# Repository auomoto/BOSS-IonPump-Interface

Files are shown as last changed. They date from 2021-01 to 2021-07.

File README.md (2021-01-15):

# BOSS-IonPump-Interface
The BOSS CCD dewars use a Modion C-1765V 2l/s ion pump with a custom vacuum fitting. This model number is not on the current modionvacuum.com website but the C-1765M looks similar.
The power supply is a Modion C-1766Q, which supplies the high voltage and also presents an analog signal indicating internal current that can be used as a vacuum pressure measurement. This power supply has an unusual 5-pin connector with a wall plug-in supply to supply power and also break out the signals.
To distribute the signals to the BOSS motion controller system (specMech) we use an interface box that supplies isolated 15 V to the two ion pumps (one on each of the two dewars) and conditions the analog signal for transmission to the control system.
[Link to the interface board description](https://docs.google.com/document/d/1ESppHA3kPF6aFfvCehlsRecCQ0mpgMWIIbT9OZ6ddFA/edit#)

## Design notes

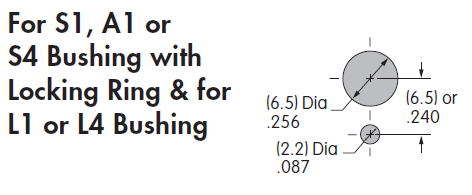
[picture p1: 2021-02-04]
Hardware/Enclosure/NKK Switch Panel Opening.png

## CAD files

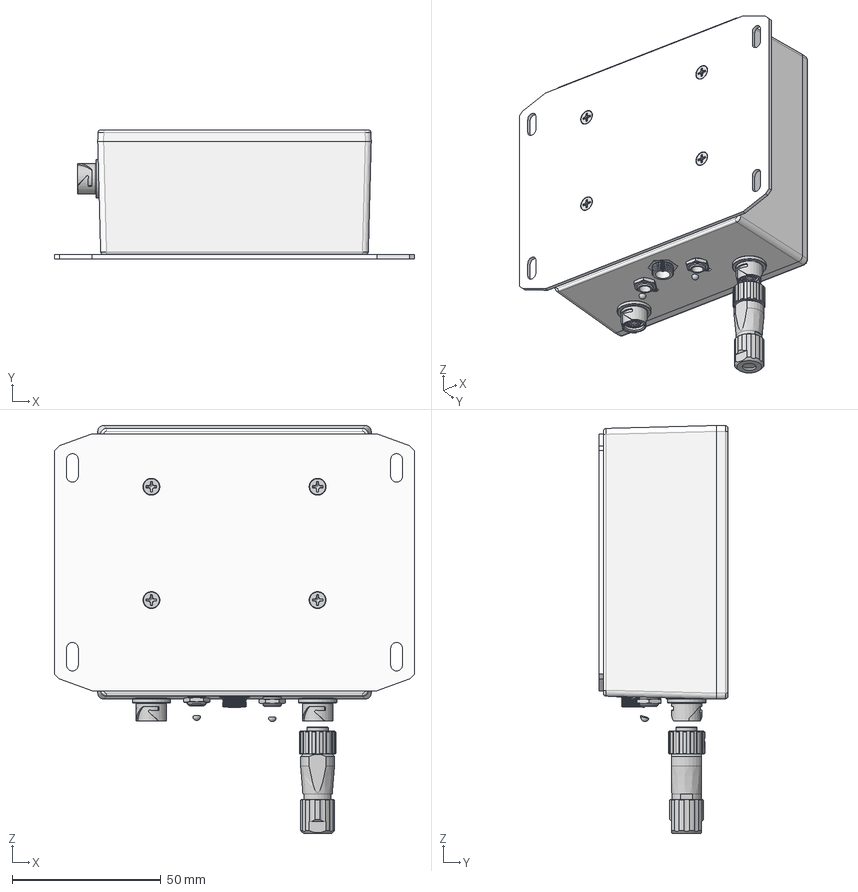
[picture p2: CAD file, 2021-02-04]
Hardware/Enclosure/BOSS Ion Pump Interface Assembly v27.step
121.2 x 43.5 x 137.2 mm
1/4 inch 91771A106_18-8 SS FLAT HEAD PHILLIPS MACHINE SCREW x 4
3/8 inch 91115A509_18-8 SS FEM THRDED HEX STANDOFF x 4
LF07WBR-6S x 2
Hirose LF07WBR-6P
CUI_DEVICES_PJ-005A
1590Y Box
1590Y Lid
1590Y Flange
LF07WBP-6P

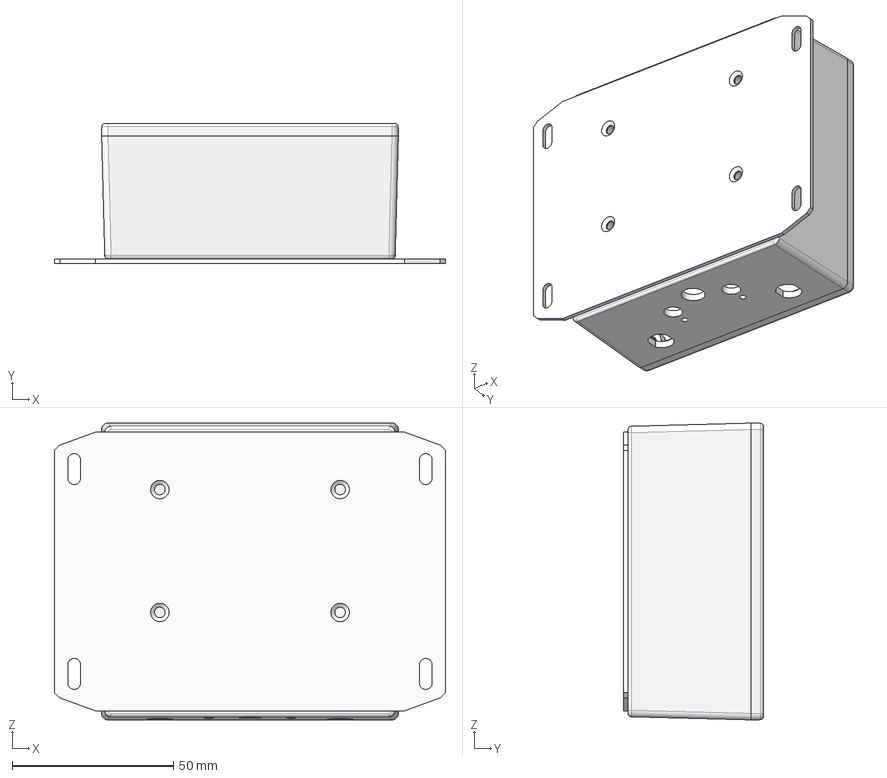
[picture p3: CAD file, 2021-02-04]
Hardware/Enclosure/1590YF Modified v1.step
121.2 x 43.5 x 92.0 mm
1590Y Box
1590Y Lid
1590Y Flange

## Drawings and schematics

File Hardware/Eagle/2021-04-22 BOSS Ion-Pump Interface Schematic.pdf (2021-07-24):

J2

# 2021-04-22 BOSS-Ion-Pump-Interface

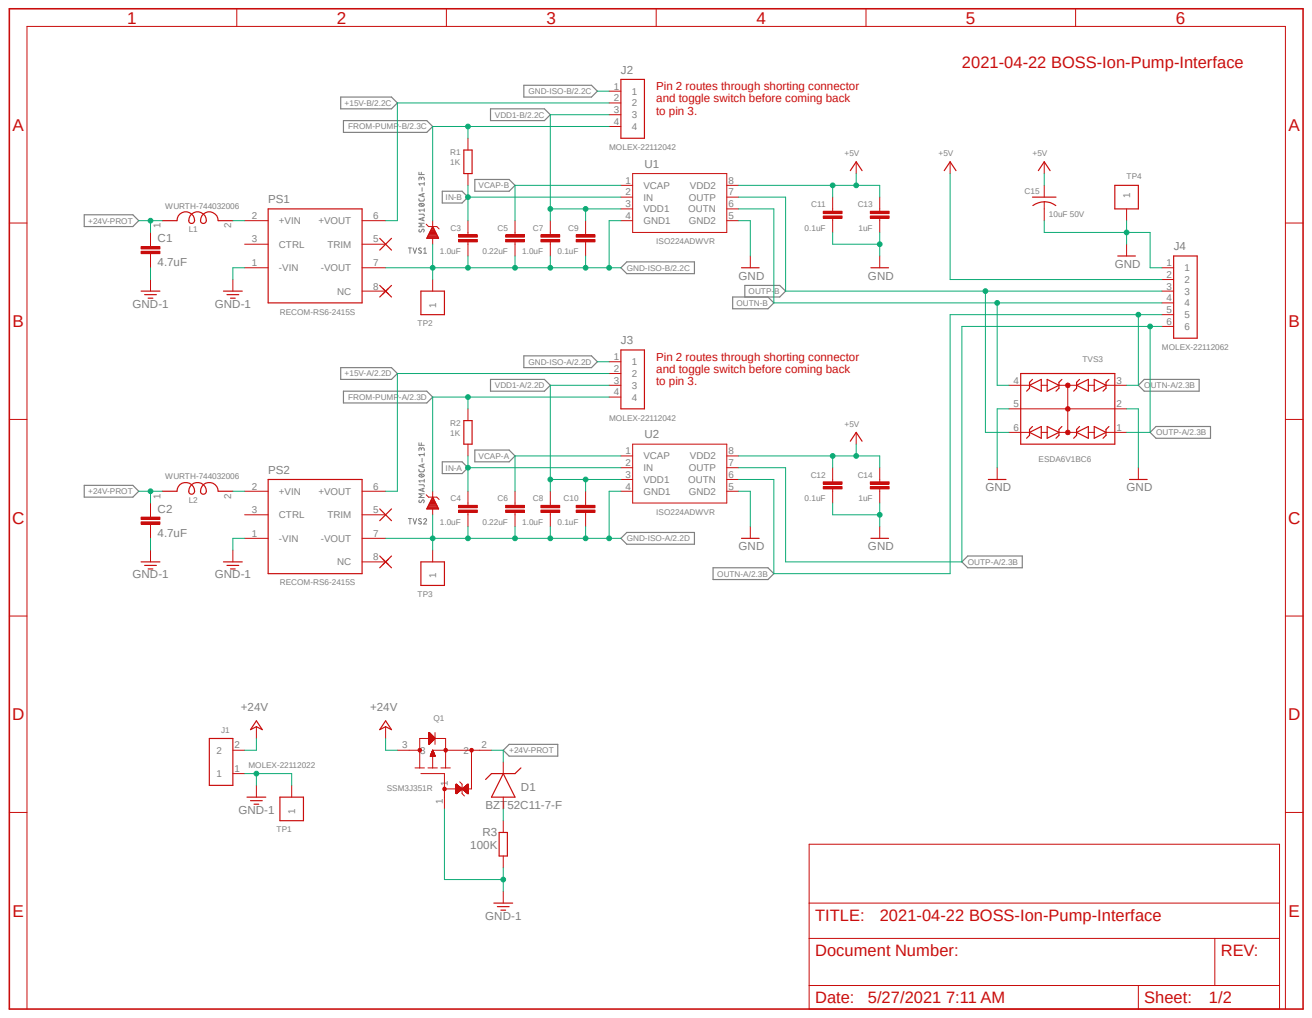
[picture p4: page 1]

2021-04-22 BOSS-Ion-Pump-Interface

Document Number: | REV:

Date: 5/27/2021 7:11 AM | Sheet: 1/2

A

A

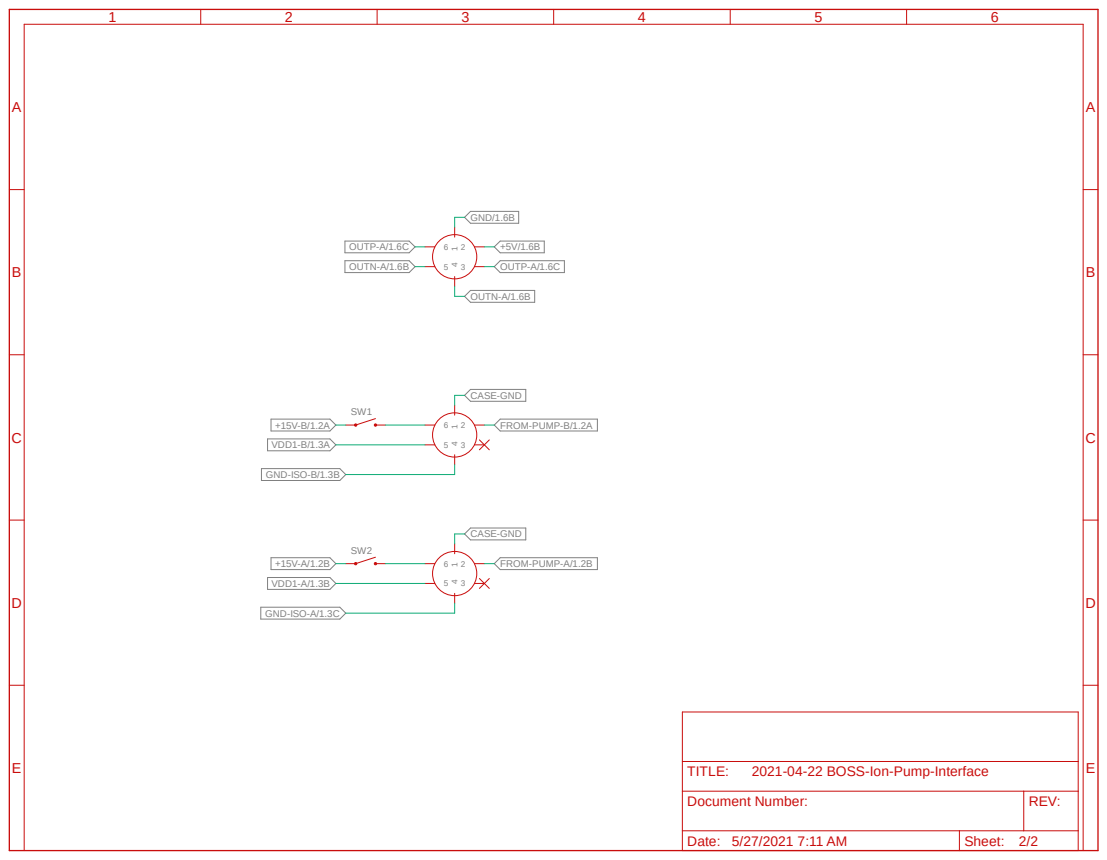
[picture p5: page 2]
VDD1-B/1.3A; GND-ISO-B/1.3B; FROM-PUMP-B/1.2A; CASE-GND; VDD1-A/1.3B; GND-ISO-A/1.3C; FROM-PUMP-A/1.2B; GND/1.6B; OUTP-A/1.6C; OUTN-A/1.6B; TITLE:

2021-04-22 BOSS-Ion-Pump-Interface

Document Number: | REV:

Date: 5/27/2021 7:11 AM | Sheet: 2/2

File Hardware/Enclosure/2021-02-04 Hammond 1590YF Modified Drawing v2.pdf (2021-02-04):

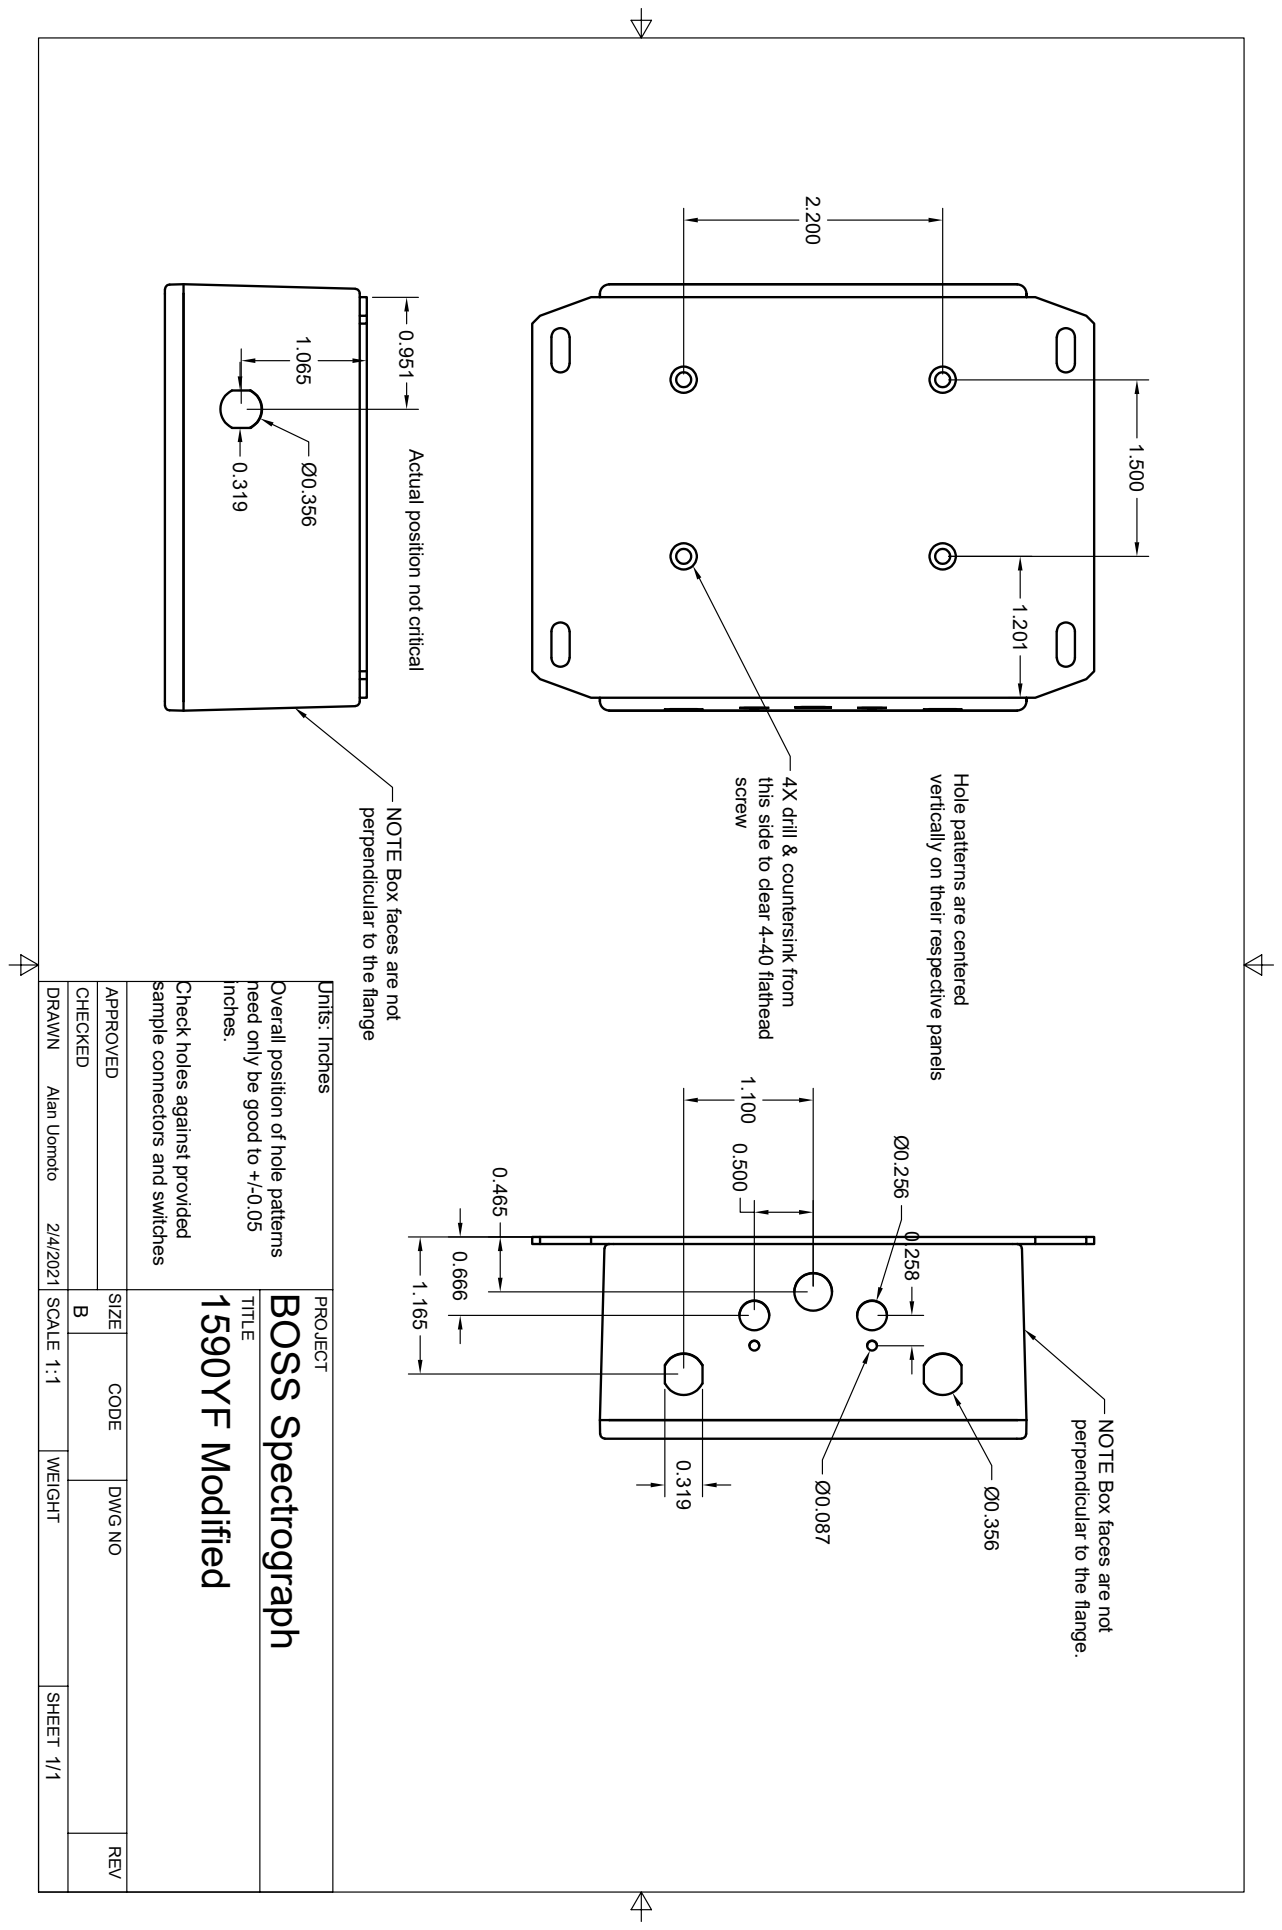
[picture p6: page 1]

TITLE PROJECT DRAWN CHECKED APPROVED SCALE WEIGHT SHEET DWG NO REV CODE SIZE 1/1 1:1 2/4/2021 Alan Uomoto B1590YF Modified BOSS Spectrograph 1.500 2.200 1.201 0.319 Ø0.356 1.065 0.465 0.6661.165 0.500 1.100 Ø0.356 Ø0.256 Ø0.087 0.258 0.319 0.951 vertically on their respective panels Hole patterns are centered Actual position not critical screw this side to clear 4-40 flathead 4X drill & countersink fromsample connectors and switches Check holes against provided inches. need only be good to +/-0.05 Overall position of hole patterns Units: Inches perpendicular to the flange. NOTE Box faces are not perpendicular to the flange NOTE Box faces are not

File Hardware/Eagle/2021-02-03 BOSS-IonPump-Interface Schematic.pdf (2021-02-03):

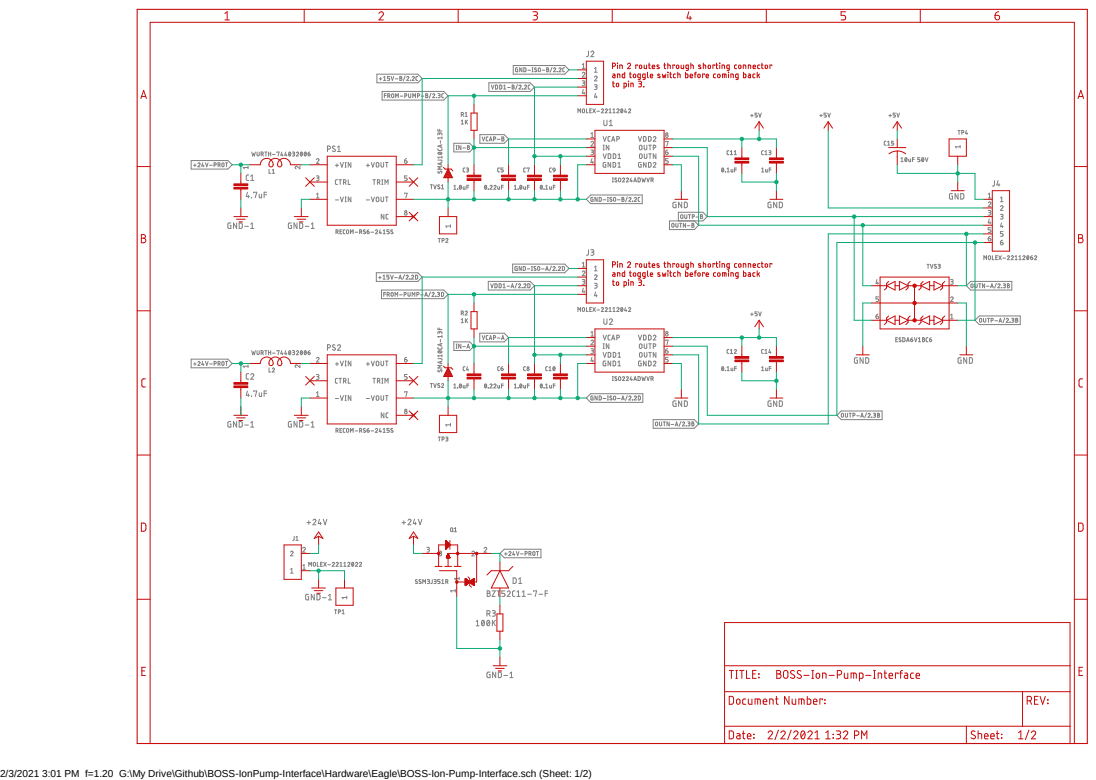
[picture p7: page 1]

2/3/2021 3:01 PM f=1.20 G:\My Drive\Github\BOSS-IonPump-Interface\Hardware\Eagle\BOSS-Ion-Pump-Interface.sch (Sheet: 1/2)

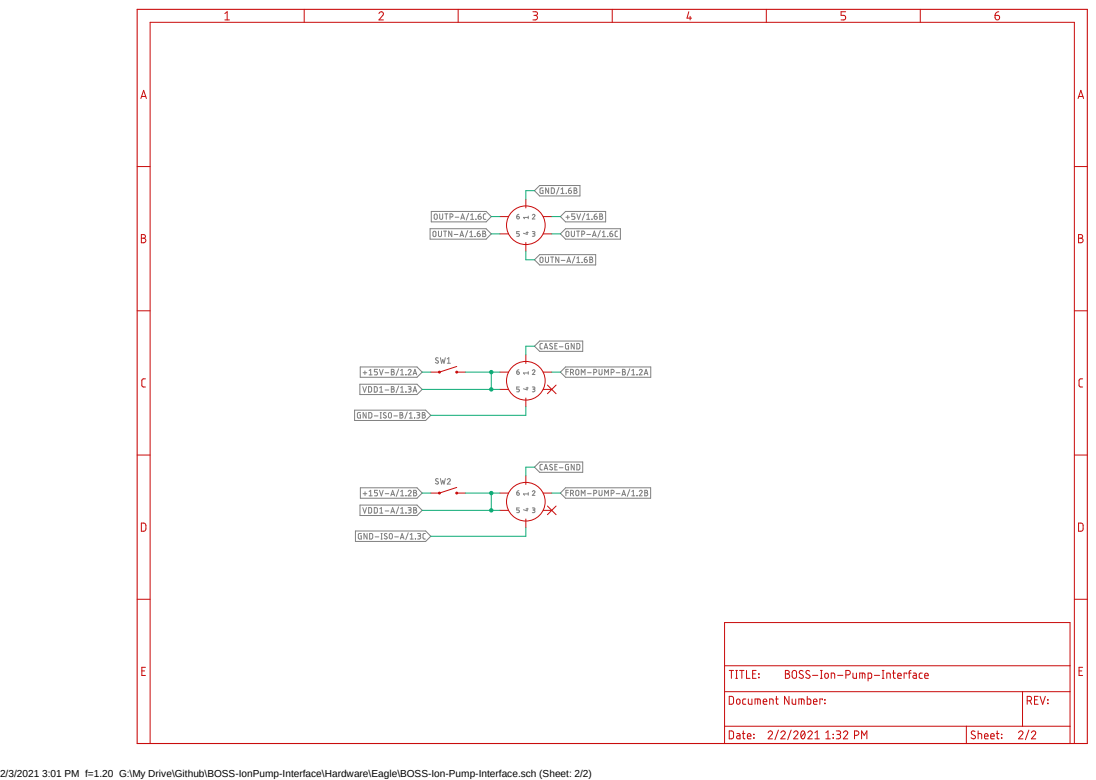
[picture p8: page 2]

2/3/2021 3:01 PM f=1.20 G:\My Drive\Github\BOSS-IonPump-Interface\Hardware\Eagle\BOSS-Ion-Pump-Interface.sch (Sheet: 2/2)

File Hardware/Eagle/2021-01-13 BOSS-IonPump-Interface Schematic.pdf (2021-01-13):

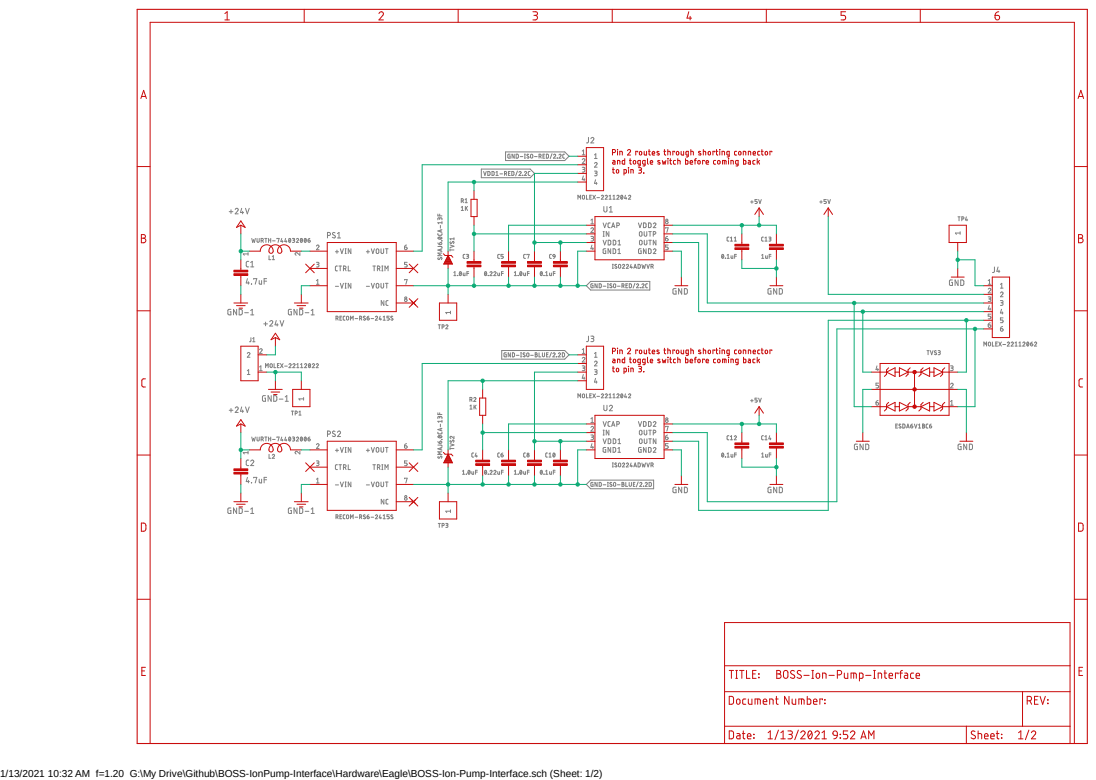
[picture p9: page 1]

1/13/2021 10:32 AM f=1.20 G:\My Drive\Github\BOSS-IonPump-Interface\Hardware\Eagle\BOSS-Ion-Pump-Interface.sch (Sheet: 1/2)

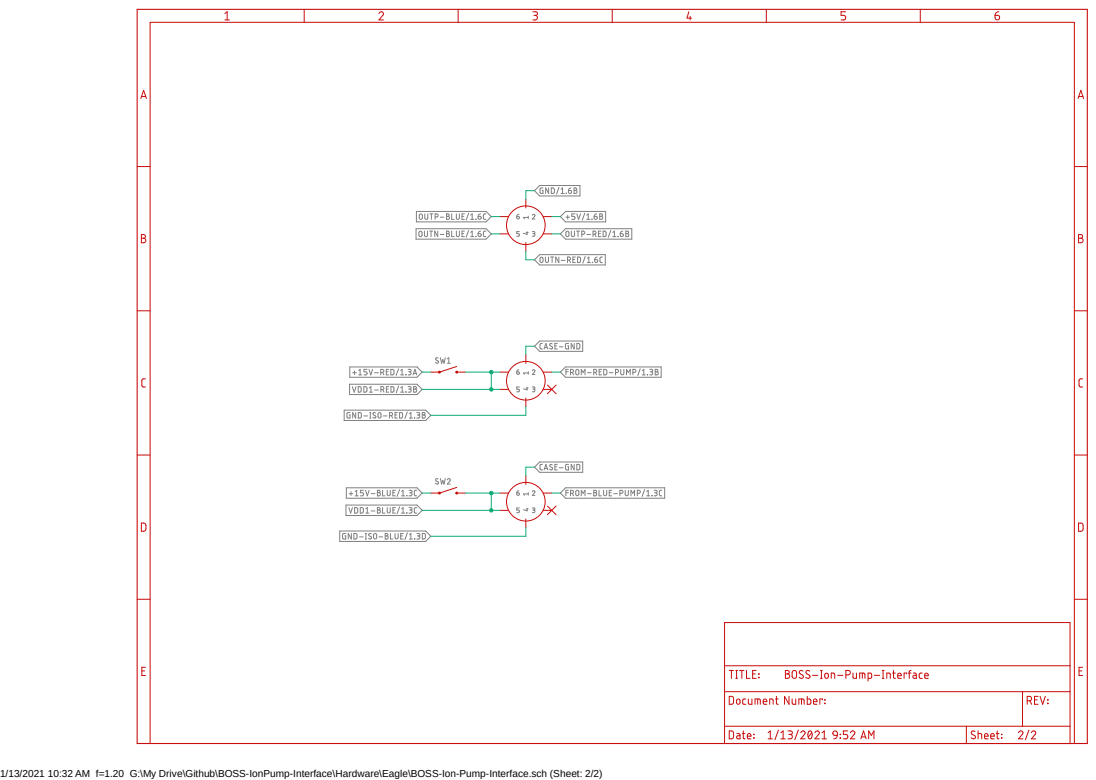
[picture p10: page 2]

1/13/2021 10:32 AM f=1.20 G:\My Drive\Github\BOSS-IonPump-Interface\Hardware\Eagle\BOSS-Ion-Pump-Interface.sch (Sheet: 2/2)

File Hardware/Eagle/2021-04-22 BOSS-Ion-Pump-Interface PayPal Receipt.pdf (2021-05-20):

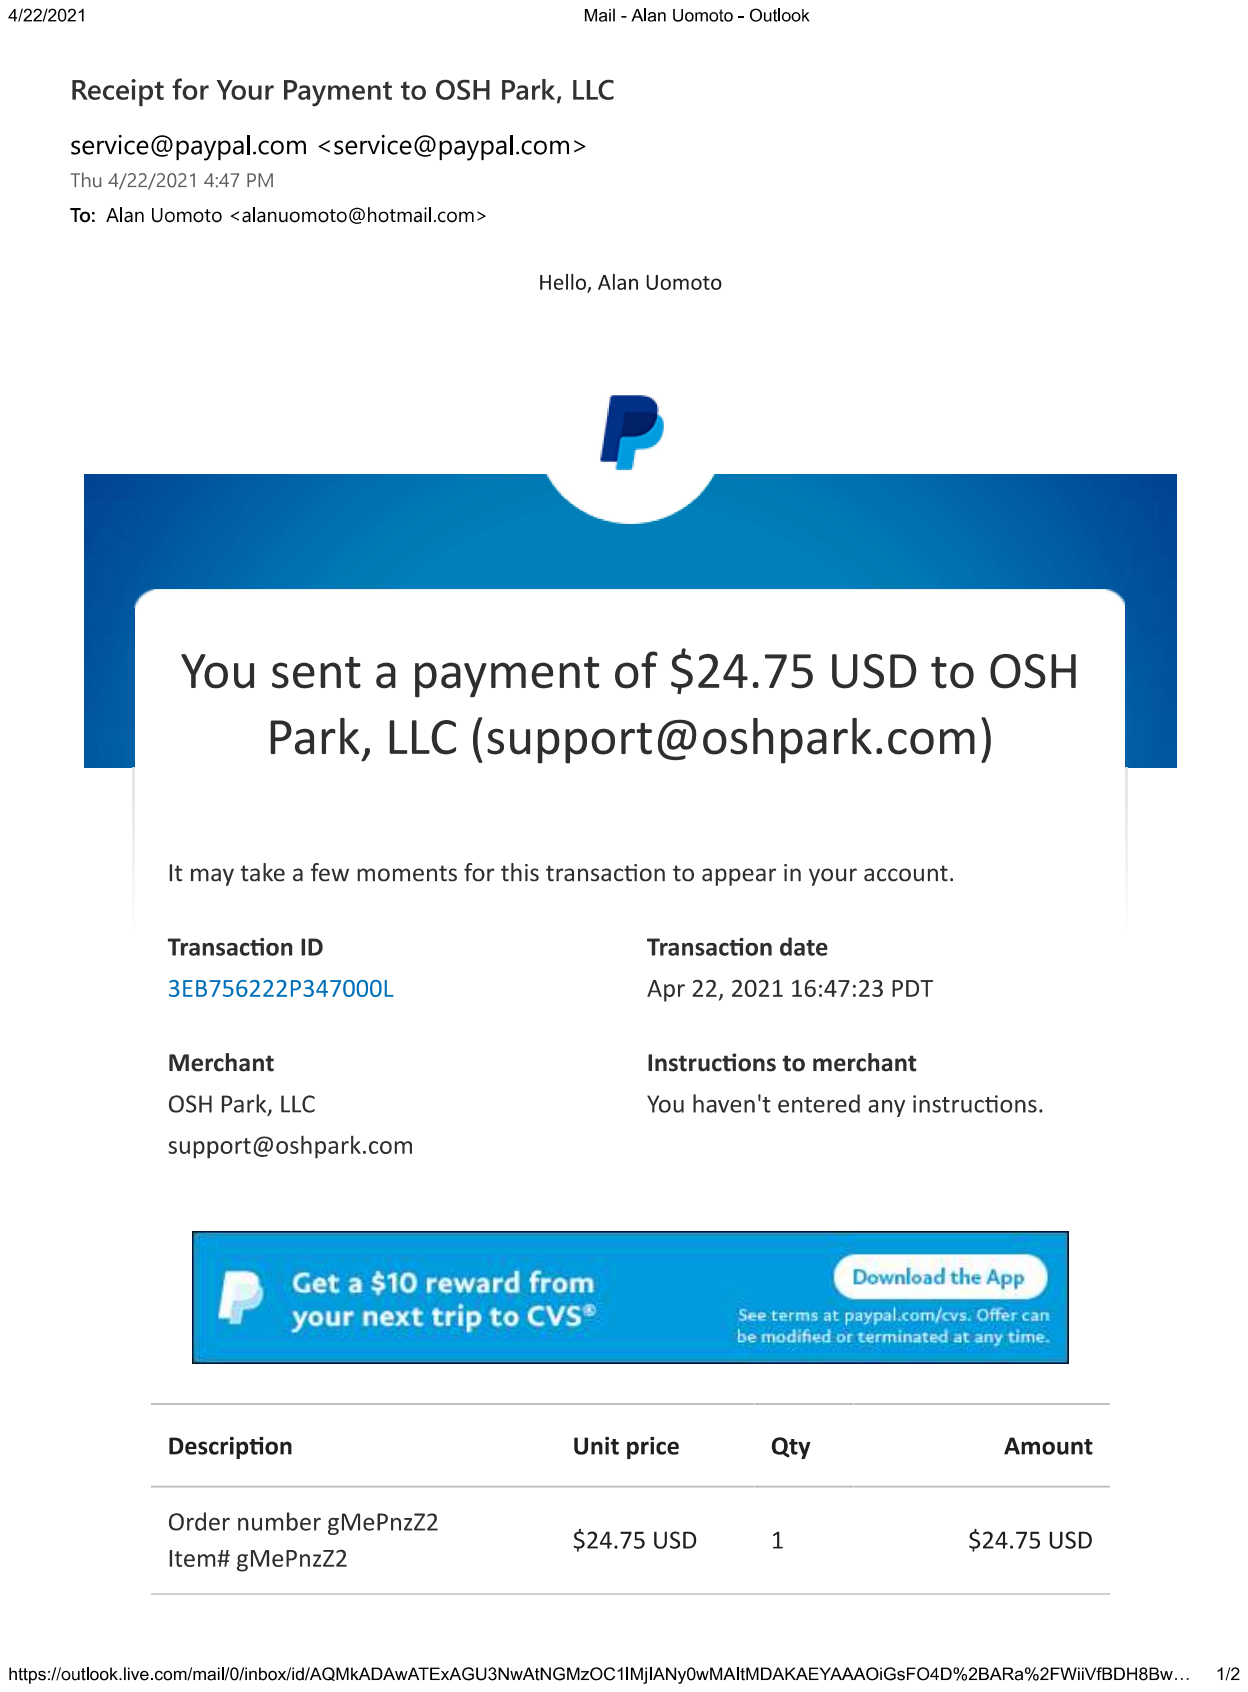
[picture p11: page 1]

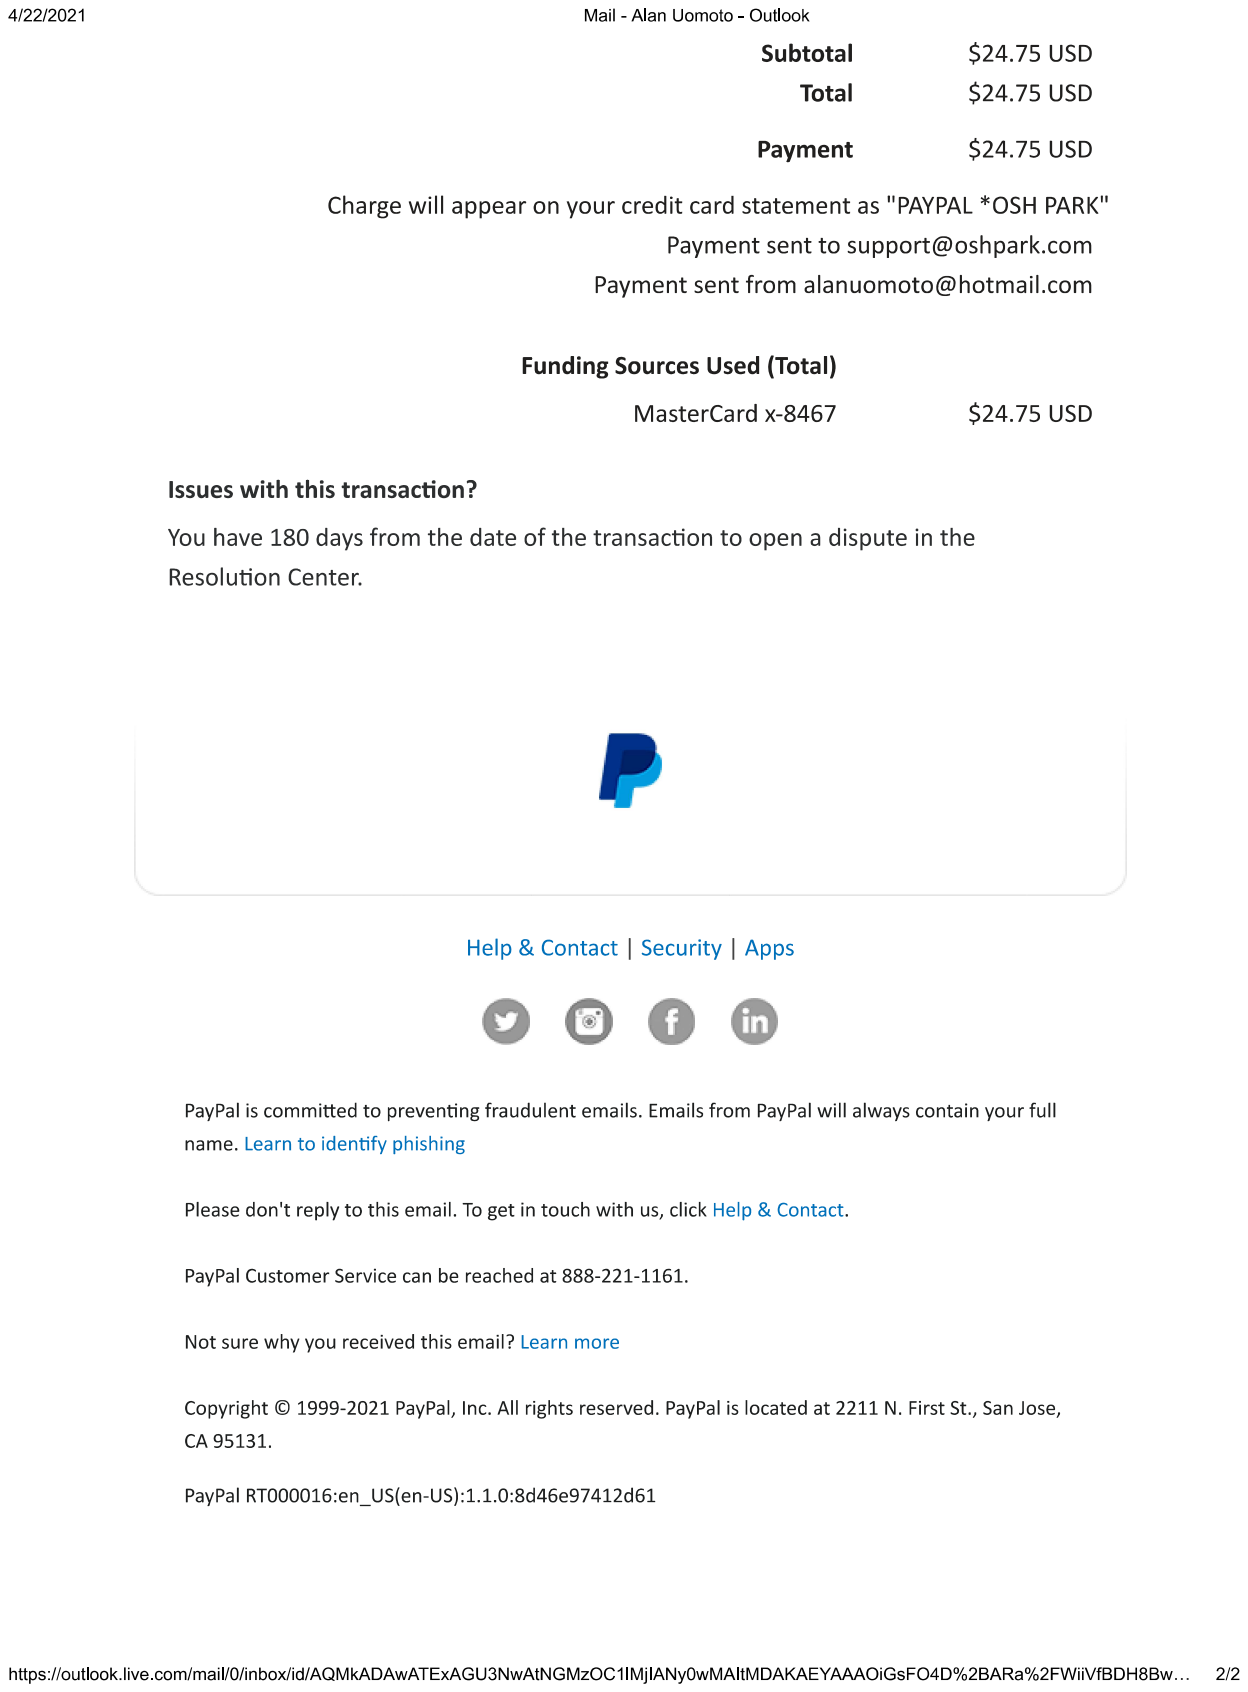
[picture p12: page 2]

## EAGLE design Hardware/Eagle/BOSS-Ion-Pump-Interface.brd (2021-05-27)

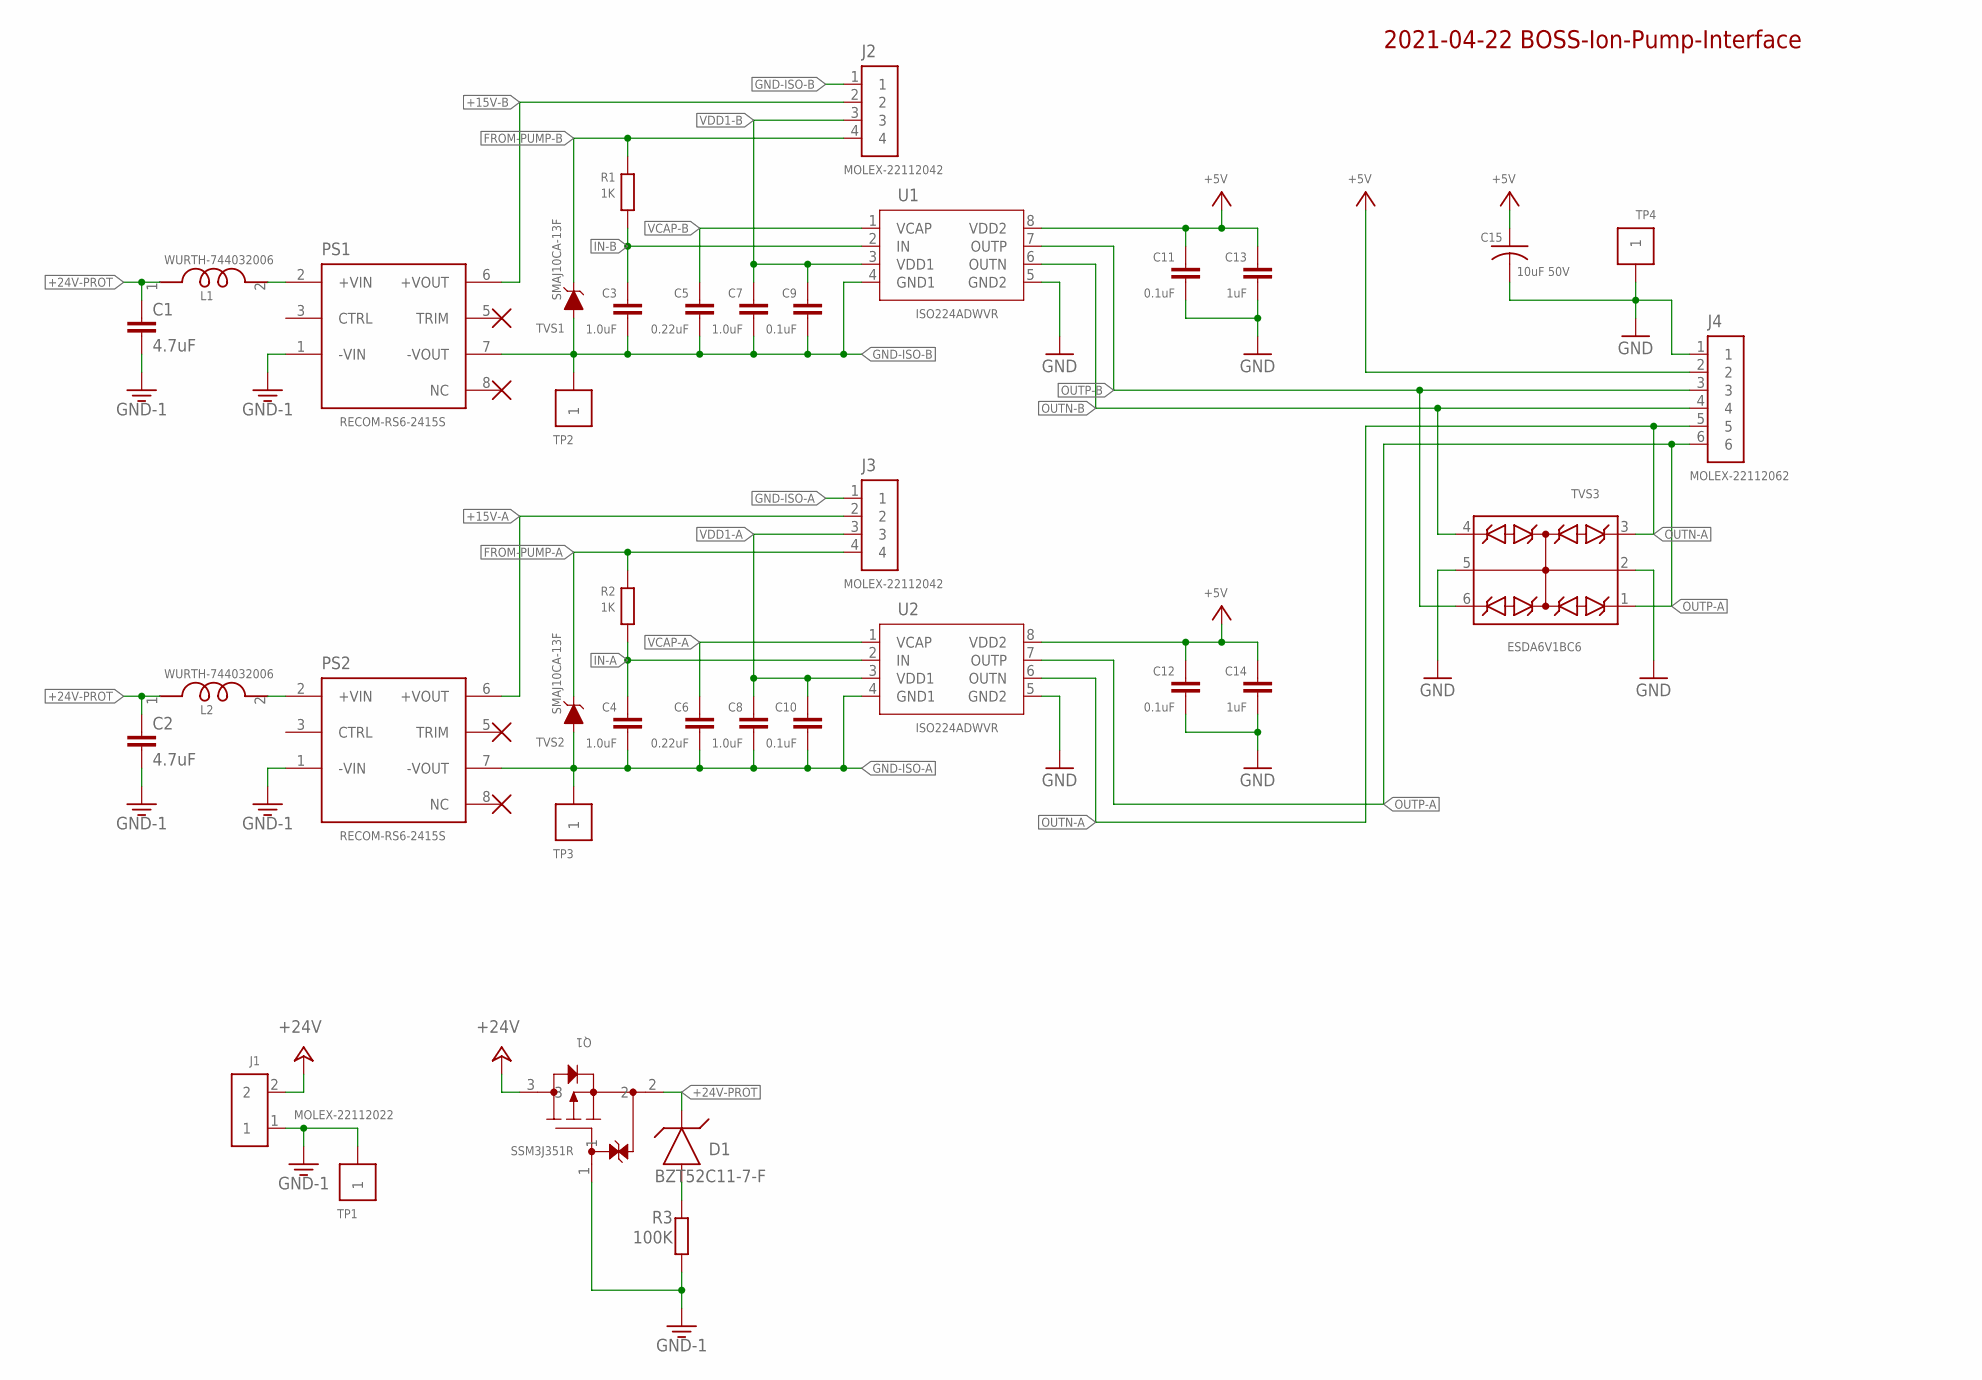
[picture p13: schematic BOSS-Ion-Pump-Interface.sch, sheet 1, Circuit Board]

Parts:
C1, C2: 4.7uF; C1206
C3, C4: 1.0uF; C0805
C5, C6: 0.22uF; C1206
C7, C8: 1.0uF; C1206
C9, C10: 0.1uF; C1206
C11, C12: 0.1uF; C0805
C13, C14: 1uF; C0805
C15: 10uF 50V; C1210
D1: BZT52C11-7-F; SOD123_DIO
J1: MOLEX-22112022; 1X02-MOLEX-22112022
J2, J3: MOLEX-22112042; 1X04-MOLEX-22112042
J4: MOLEX-22112062; 1X06-MOLEX-22112062
L1, L2: WURTH-744032006; WURTH-1210-INDUCTOR
PS1, PS2: RECOM-RS6-2415S; CONV_RS6-2415S
Q1: SSM3J351R; SOT-23F_TOS
R1, R2: 1K; R0805
R3: 100K; R0805
TP1, TP2, TP3, TP4: TP5000-TESTPOINT-BLK
TVS1, TVS2: SMAJ10CA-13F; SMA_DIO-M
TVS3: ESDA6V1BC6; SOT95P280X145-6N
U1, U2: ISO224ADWVR; DWV8_TEX

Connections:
+5V: C11.1, C12.1, C13.1, C14.1, C15.1, J4.2, U1.8 (VDD2), U2.8 (VDD2)
+15V-A: J3.2, PS2.6 (+VOUT)
+15V-B: J2.2, PS1.6 (+VOUT)
+24V: J1.2, Q1.3
+24V-PROT: C1.1, C2.1, D1.1 (C), L1.1, L2.1, Q1.2
+VIN-A: L2.2, PS2.2 (+VIN)
+VIN-B: L1.2, PS1.2 (+VIN)
FROM-PUMP-A: J3.4, R2.1, TVS2.1 (C)
FROM-PUMP-B: J2.4, R1.1, TVS1.1 (C)
GND: C11.2, C12.2, C13.2, C14.2, C15.2, J4.1, TP4.P$1, TVS3.2 (CC1), TVS3.5 (CC2), U1.5 (GND2), U2.5 (GND2)
GND-1: C1.2, C2.2, J1.1, PS1.1 (-VIN), PS2.1 (-VIN), Q1.1, R3.1, TP1.P$1
GND-ISO-A: C4.2, C6.2, C8.2, C10.2, J3.1, PS2.7 (-VOUT), TP3.P$1, TVS2.2 (A), U2.4 (GND1)
GND-ISO-B: C3.2, C5.2, C7.2, C9.2, J2.1, PS1.7 (-VOUT), TP2.P$1, TVS1.2 (A), U1.4 (GND1)
IN-A: C4.1, R2.2, U2.2 (IN)
IN-B: C3.1, R1.2, U1.2 (IN)
OUTN-A: J4.5, TVS3.3 (C2), U2.6 (OUTN)
OUTN-B: J4.4, TVS3.4 (C3), U1.6 (OUTN)
OUTP-A: J4.6, TVS3.1 (C1), U2.7 (OUTP)
OUTP-B: J4.3, TVS3.6 (C4), U1.7 (OUTP)
REVERSE-POL-ZENER: D1.2 (A), R3.2
VCAP-A: C6.1, U2.1 (VCAP)
VCAP-B: C5.1, U1.1 (VCAP)
VDD1-A: C8.1, C10.1, J3.3, U2.3 (VDD1)
VDD1-B: C7.1, C9.1, J2.3, U1.3 (VDD1)

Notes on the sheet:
2021-04-22 BOSS-Ion-Pump-Interface

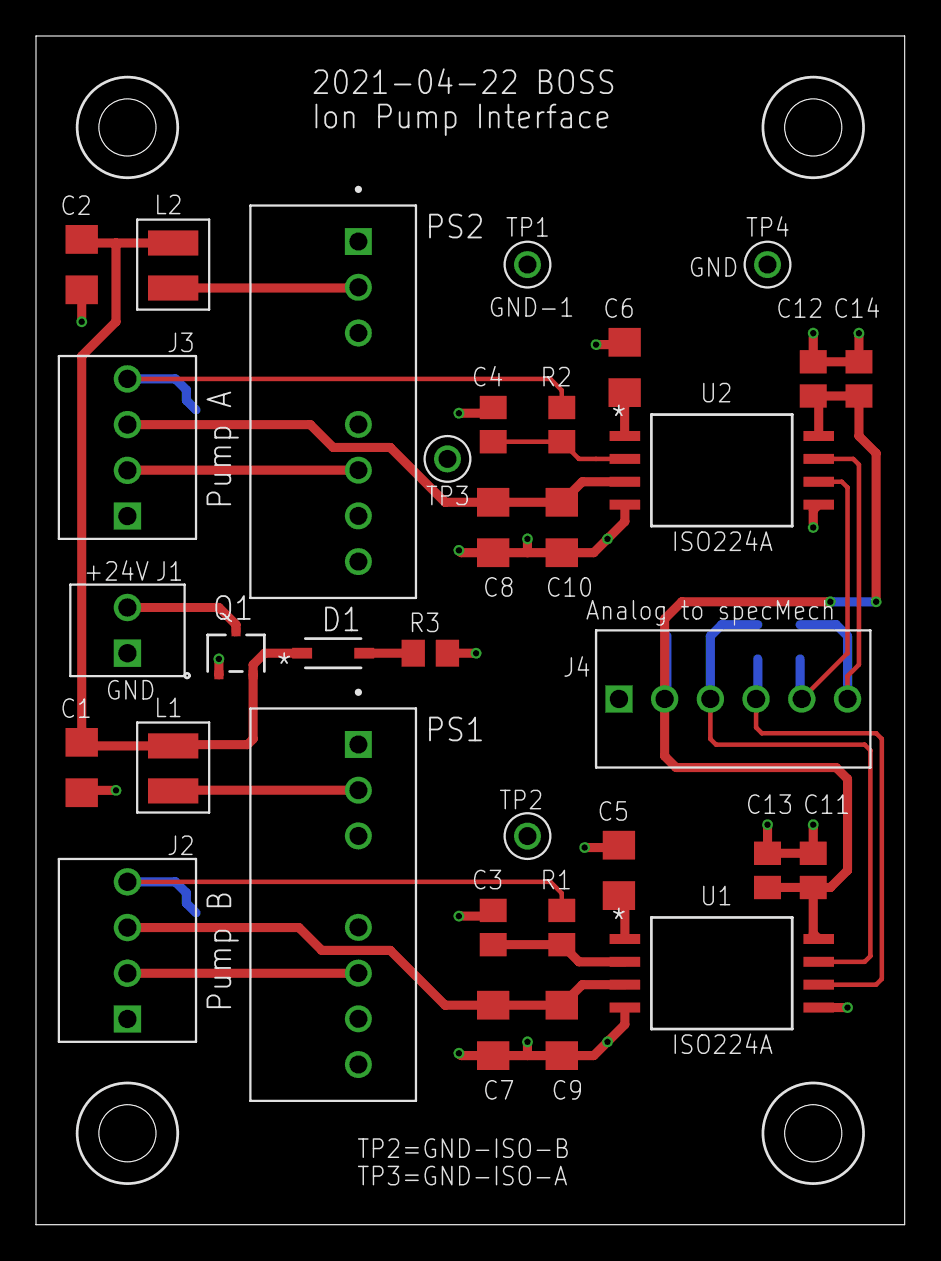
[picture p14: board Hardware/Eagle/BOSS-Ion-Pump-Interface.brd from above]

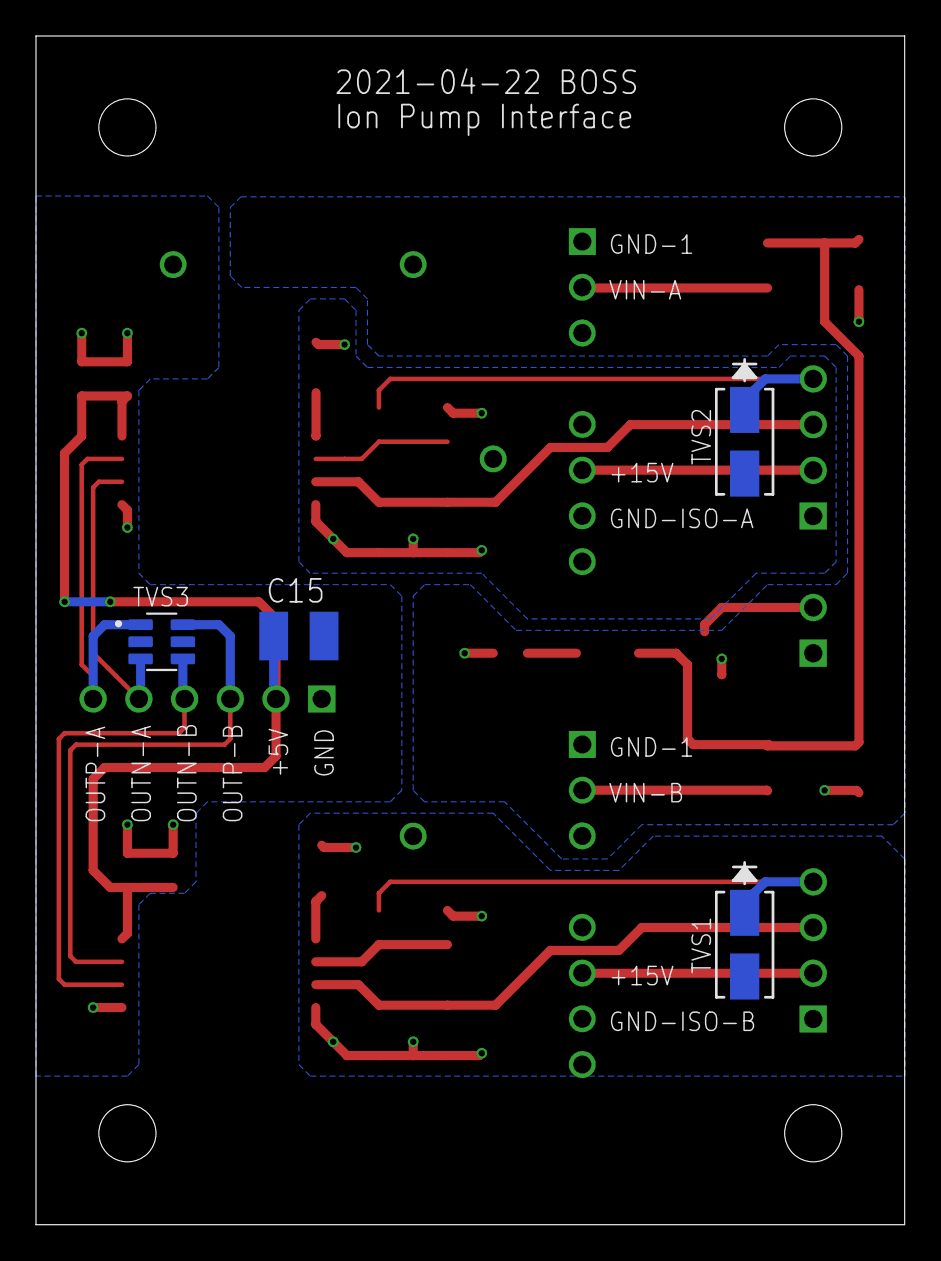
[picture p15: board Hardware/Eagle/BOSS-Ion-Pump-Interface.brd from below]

Board: 2 copper layers, 48.3 x 66.0 mm, 37 parts (4 on the bottom side), 24 nets.

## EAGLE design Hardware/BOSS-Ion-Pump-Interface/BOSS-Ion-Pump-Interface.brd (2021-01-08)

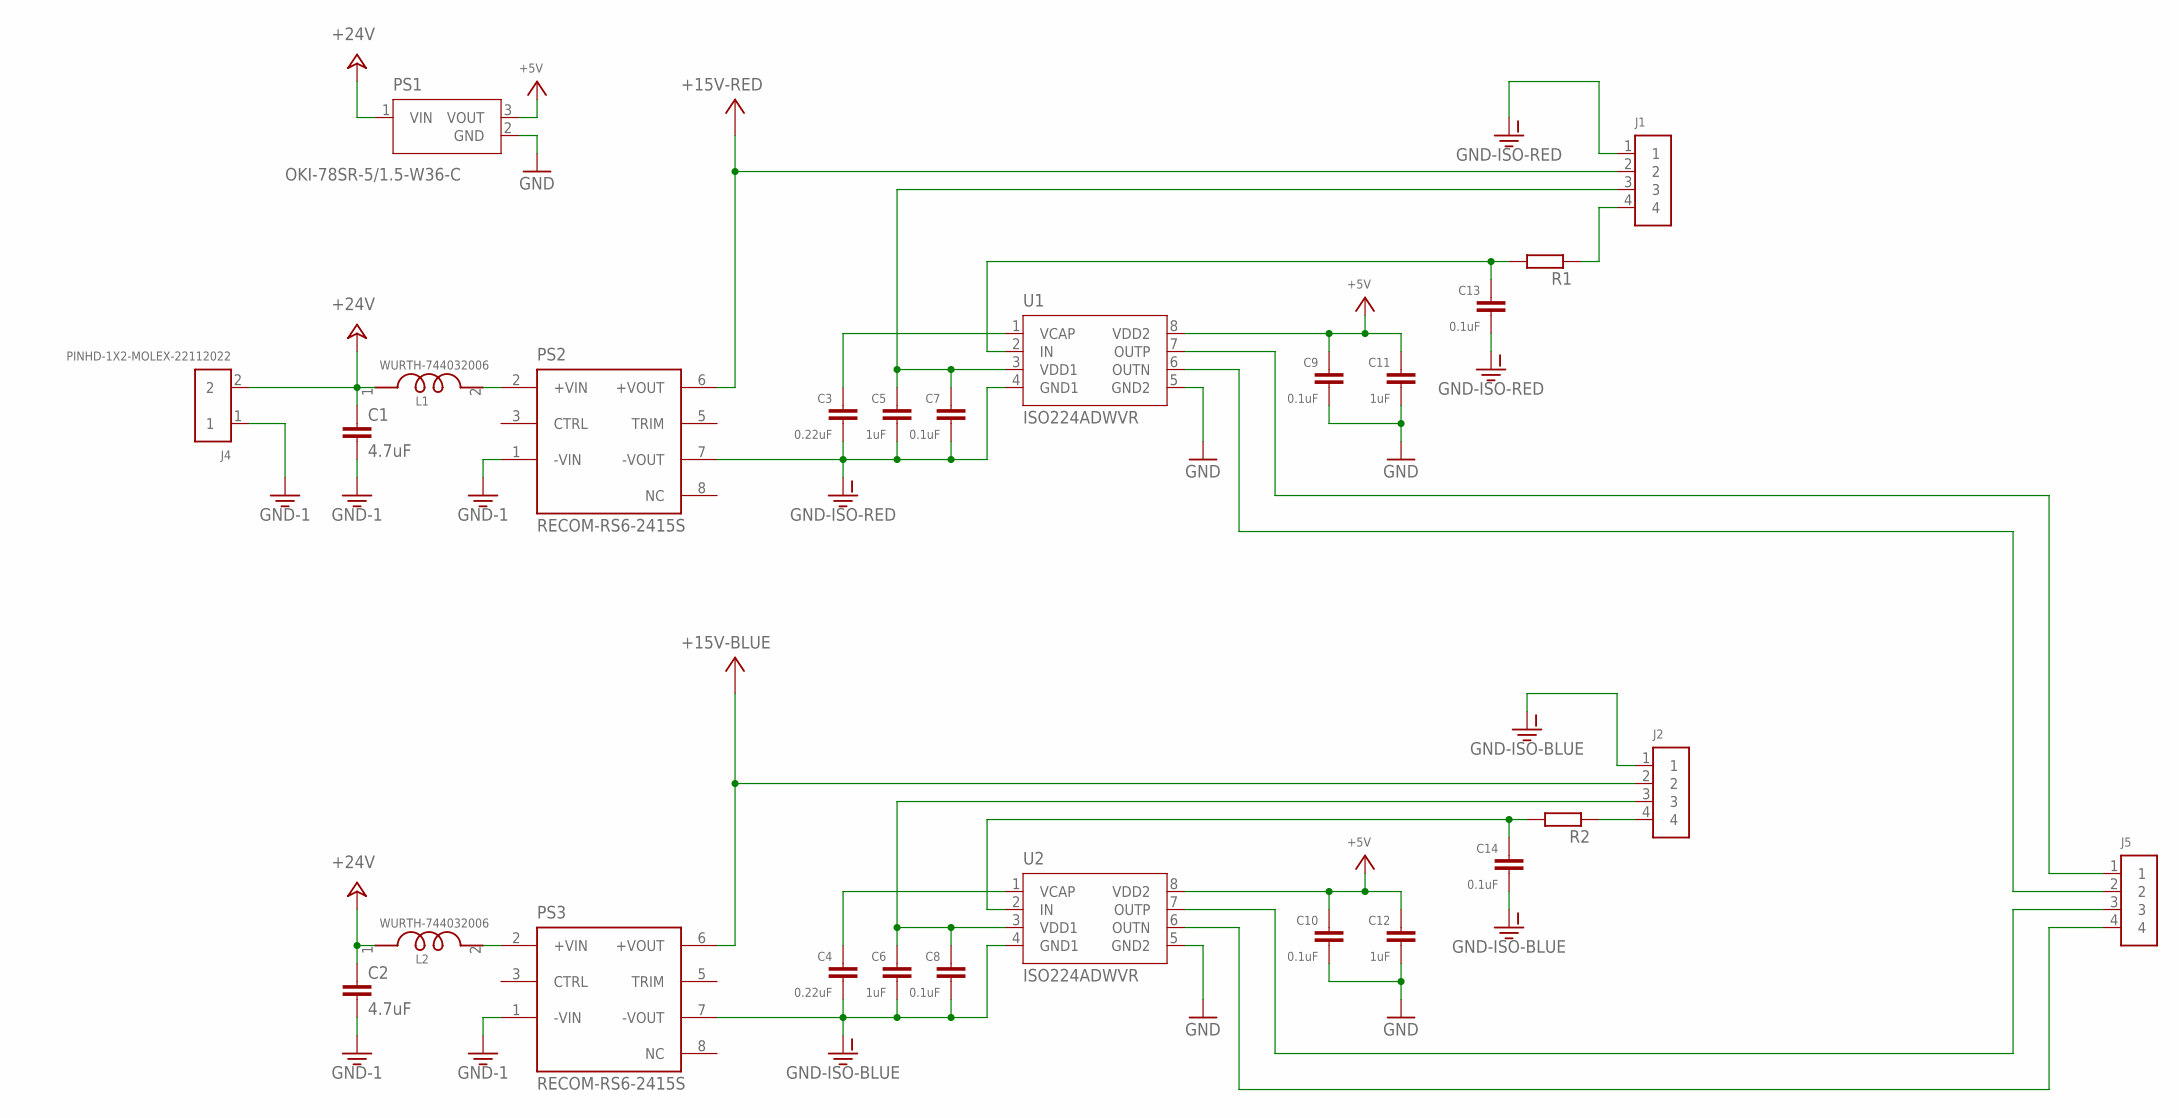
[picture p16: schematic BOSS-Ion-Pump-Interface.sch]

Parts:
C1, C2: 4.7uF; C1206
C3, C4: 0.22uF; C0805
C5, C6, C11, C12: 1uF; C0805
C7, C8, C9, C10, C13, C14: 0.1uF; C0805
J1, J2, J5: PINHD-1X4-MOLEX-22112042; 1X04-MOLEX-22112042
J4: PINHD-1X2-MOLEX-22112022; 1X02-MOLEX-22112022
L1, L2: WURTH-744032006; WURTH-1210-INDUCTOR
PS1: OKI-78SR-5/1.5-W36-C; CONV_OKI-78SR-5/1.5-W36-C
PS2, PS3: RECOM-RS6-2415S; CONV_RS6-2415S
R1, R2: R-EU_R0805; R0805
U1, U2: ISO224ADWVR; DWV8_TEX

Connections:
+5V: C9.1, C10.1, C11.1, C12.1, PS1.3 (VOUT), U1.8 (VDD2), U2.8 (VDD2)
+15V-BLUE: J2.2, PS3.6 (+VOUT)
+15V-RED: J1.2, PS2.6 (+VOUT)
+24V: C1.1, C2.1, J4.2, L1.1, L2.1, PS1.1 (VIN)
BLUE+: J5.3, U2.7 (OUTP)
BLUE-: J5.4, U2.6 (OUTN)
GND: C9.2, C10.2, C11.2, C12.2, PS1.2 (GND), U1.5 (GND2), U2.5 (GND2)
GND-1: C1.2, C2.2, J4.1, PS2.1 (-VIN), PS3.1 (-VIN)
GND-ISO-1: C3.2, C5.2, C7.2, C13.2, J1.1, PS2.7 (-VOUT), U1.4 (GND1)
GND-ISO-2: C4.2, C6.2, C8.2, C14.2, J2.1, PS3.7 (-VOUT), U2.4 (GND1)
IN-BLUE: C14.1, R2.2, U2.2 (IN)
IN-RED: C13.1, R1.2, U1.2 (IN)
unnamed: C3.1, U1.1 (VCAP)
unnamed: L1.2, PS2.2 (+VIN)
unnamed: J1.4, R1.1
unnamed: C4.1, U2.1 (VCAP)
unnamed: L2.2, PS3.2 (+VIN)
unnamed: J2.4, R2.1
RED+: J5.1, U1.7 (OUTP)
RED-: J5.2, U1.6 (OUTN)
VDD1-BLUE: C6.1, C8.1, J2.3, U2.3 (VDD1)
VDD1-RED: C5.1, C7.1, J1.3, U1.3 (VDD1)

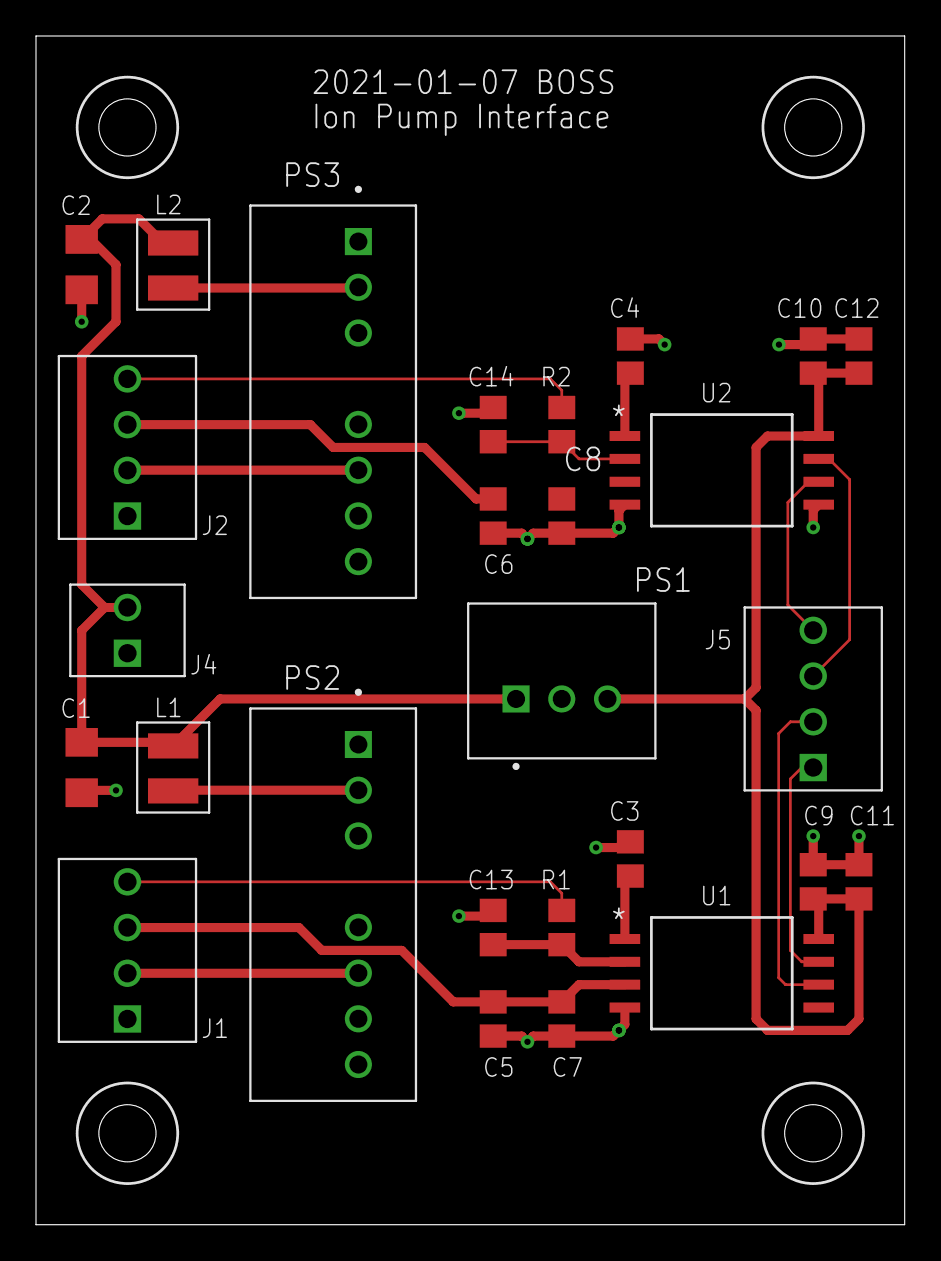
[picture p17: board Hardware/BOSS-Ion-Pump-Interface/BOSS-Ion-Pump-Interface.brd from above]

Board: 2 copper layers, 48.3 x 66.0 mm, 27 parts (0 on the bottom side), 22 nets.

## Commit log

2021-01-08 2021-01-07 version
    To do: Remove the 5V supply and get it from specMech
    [BOSS-Ion-Pump-Interface.brd, BOSS-Ion-Pump-Interface.sch]
2021-01-10 Increased capacitor voltages and changed to 1206
    [BOSS-Ion-Pump-Interface.brd, BOSS-Ion-Pump-Interface.sch]
2021-01-12 Added test points, cleaned up ERC check
    [BOSS-Ion-Pump-Interface.brd, BOSS-Ion-Pump-Interface.sch]
2021-01-13 Added external parts (switches and panel connectors)
    [BOSS-Ion-Pump-Interface.brd, BOSS-Ion-Pump-Interface.sch]
2021-01-13 Printed new schematic
    [BOSS-Ion-Pump-Interface.sch]
2021-01-15 Minor edits for upload to Fusion 360
    [BOSS-Ion-Pump-Interface.brd]
2021-01-21 Measured some dimensions; no circut or layout changes
    [BOSS-Ion-Pump-Interface.brd]
2021-01-27 Re-labeled nets, added 10uF filter on+5V in
    [BOSS-Ion-Pump-Interface.brd, BOSS-Ion-Pump-Interface.sch]
2021-01-27 minor re-routing
    [BOSS-Ion-Pump-Interface.brd]
2021-01-28 Added reverse polarity protection
    [BOSS-Ion-Pump-Interface.brd, BOSS-Ion-Pump-Interface.sch]
2021-02-02 Changed TVS diode to 10 V from 6 V and labeled reverse polarity Zener
    [BOSS-Ion-Pump-Interface.brd, BOSS-Ion-Pump-Interface.sch]
2021-02-03 Create 2021-02-03 BOSS-IonPump-Interface Schematic.pdf
2021-02-04 Exported Hammond box machining drawing and STEP files
    [1590YF Modified v1.step, BOSS Ion Pump Interface Assembly v27.step]
2021-02-04 Create NKK Switch Panel Opening.png
2021-02-20 Added names to the reverse polarity zener net
    [BOSS-Ion-Pump-Interface.brd, BOSS-Ion-Pump-Interface.sch]
2021-02-23 Changed the incorrect label on the output amp to ISO224A
    [BOSS-Ion-Pump-Interface.brd]
2021-05-20 Added wire colors to connectors
    [2021-04-22 BOSS-Ion-Pump-Interface.brd, 2021-04-22 BOSS-Ion-Pump-Interface.sch, 2021-04-22a BOSS-Ion-Pump-Interface.brd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]
2021-05-27 Minor edits to schematic
    [2021-04-22 BOSS-Ion-Pump-Interface.brd, 2021-04-22 BOSS-Ion-Pump-Interface.sch]
2021-07-24 Production version
    [BOSS-Ion-Pump-Interface.brd, BOSS-Ion-Pump-Interface.sch]

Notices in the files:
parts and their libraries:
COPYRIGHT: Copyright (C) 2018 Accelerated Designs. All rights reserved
